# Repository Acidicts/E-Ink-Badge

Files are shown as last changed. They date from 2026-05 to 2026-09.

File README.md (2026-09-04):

# E-Ink Badge

A DIY Custom Designed, Monochrome, E-Ink display badge powered by the RP2350A, inspired by the GitHub Universe 2024 conference badge.
~Kinda wanted to see how many words I could describe it with. 

<div style="width:100%; display:inline-flex">
    E-Ink Badge render 1
    E-Ink Badge render 2
</div>

*(Renders made in Fusion 360)*

<div style="width:100%;">
    <div style="width:100%; display:inline-flex">
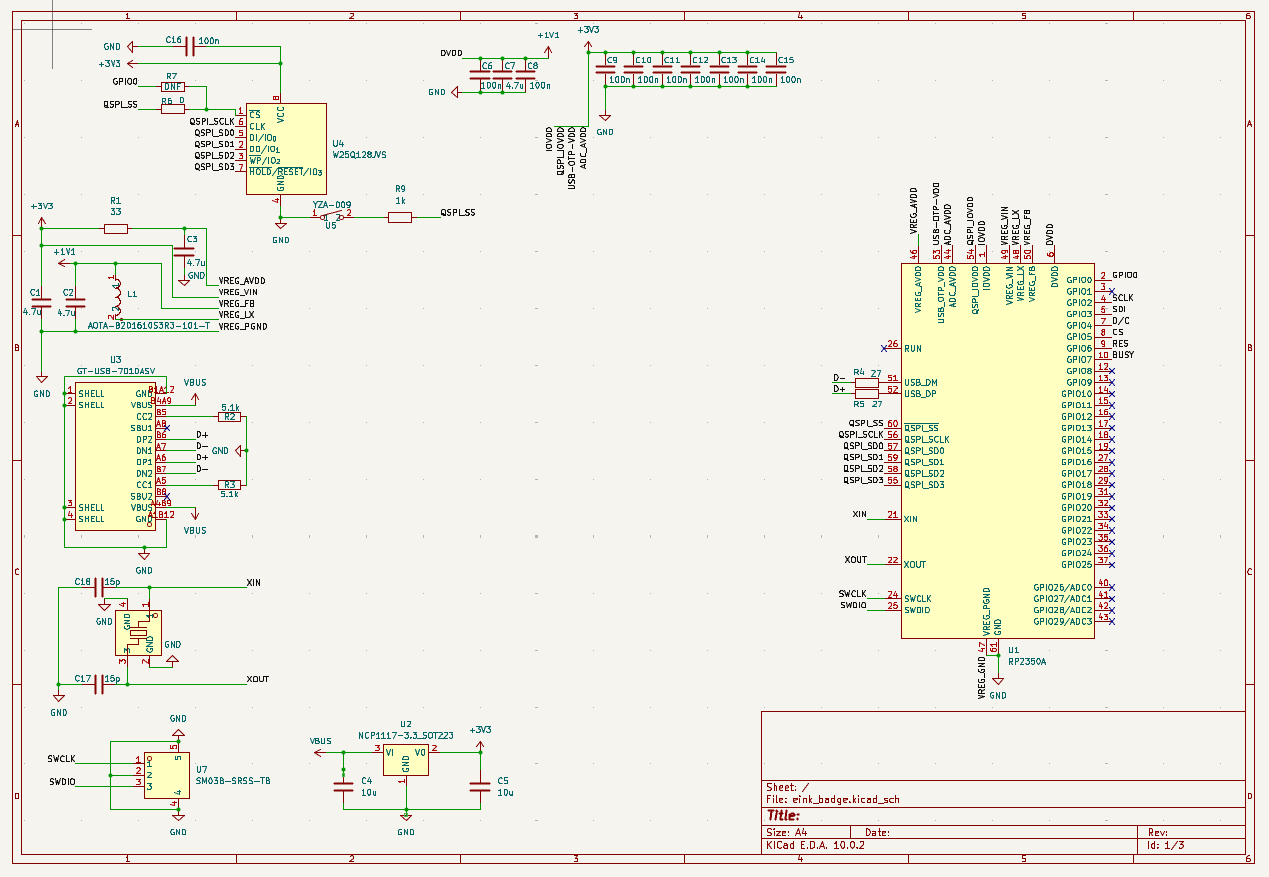
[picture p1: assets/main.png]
Assembled badge, main view
        
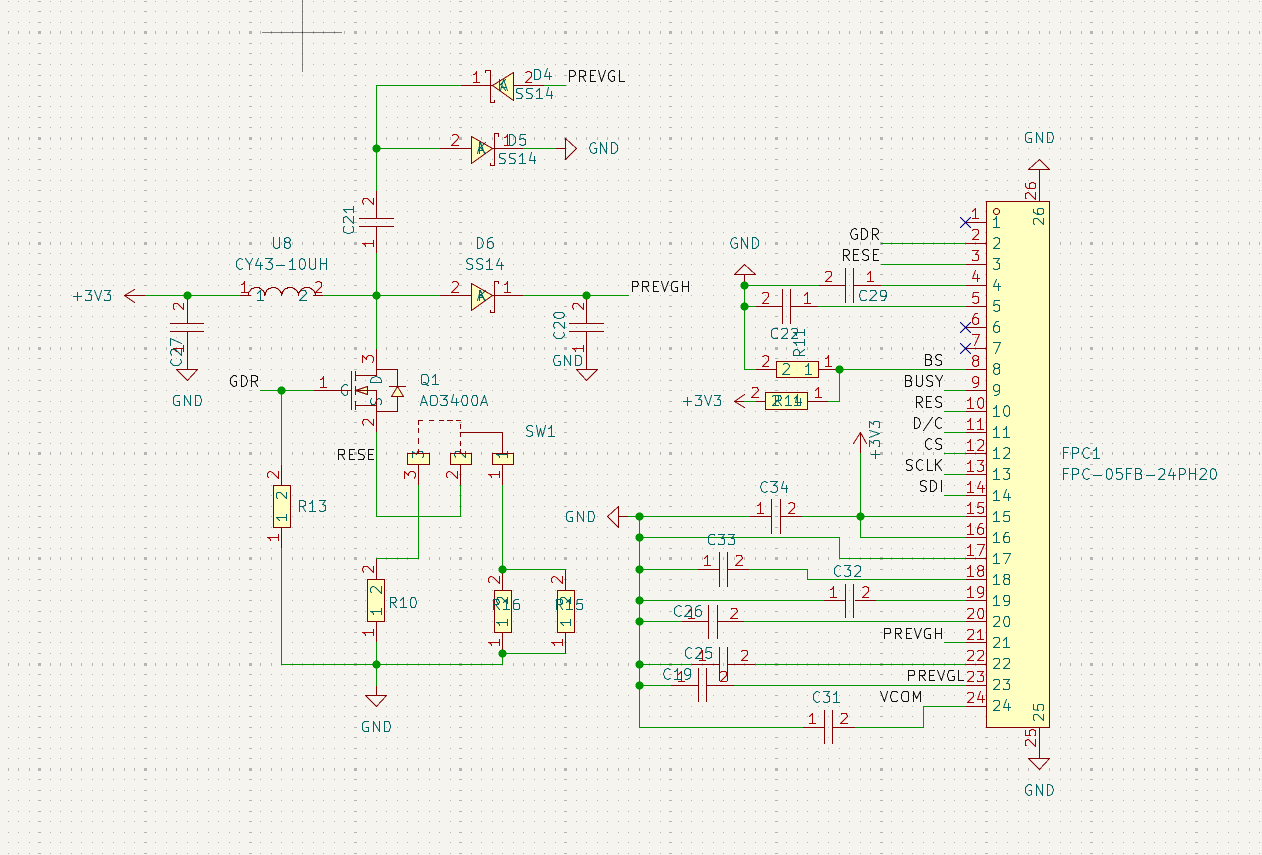
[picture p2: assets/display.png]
E-Ink display detail
        
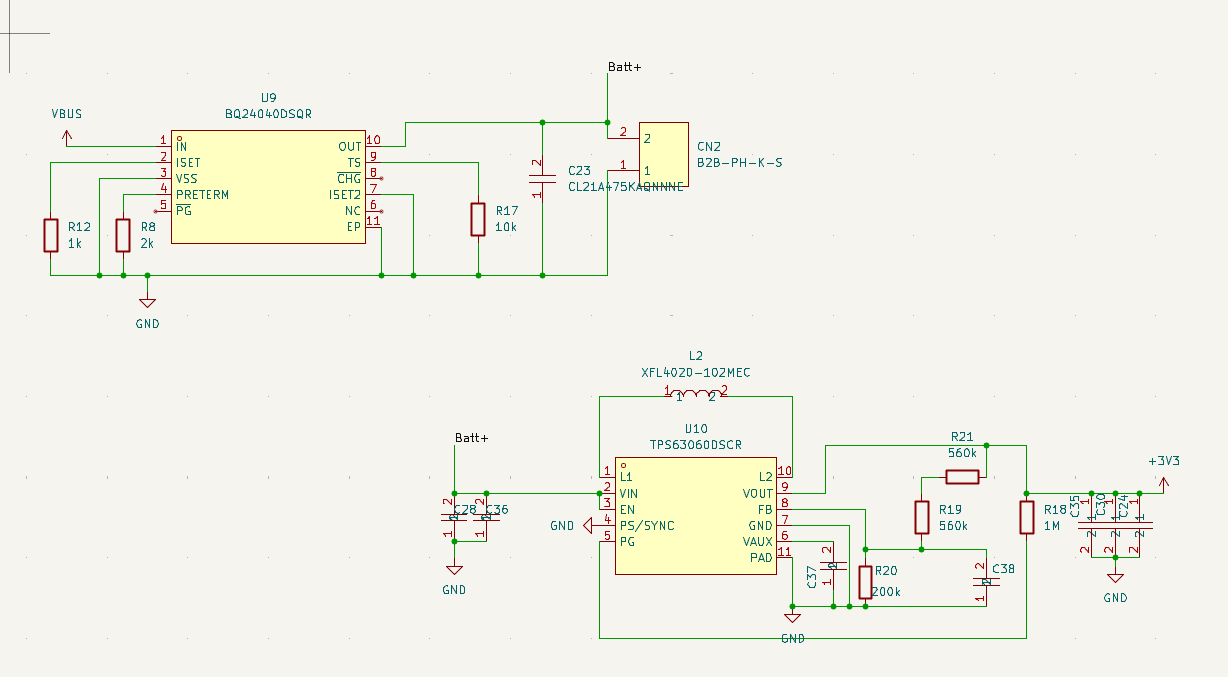
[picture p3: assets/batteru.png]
Battery mounting detail
        
    </div>
    <div style="width:100%; display:inline-flex">
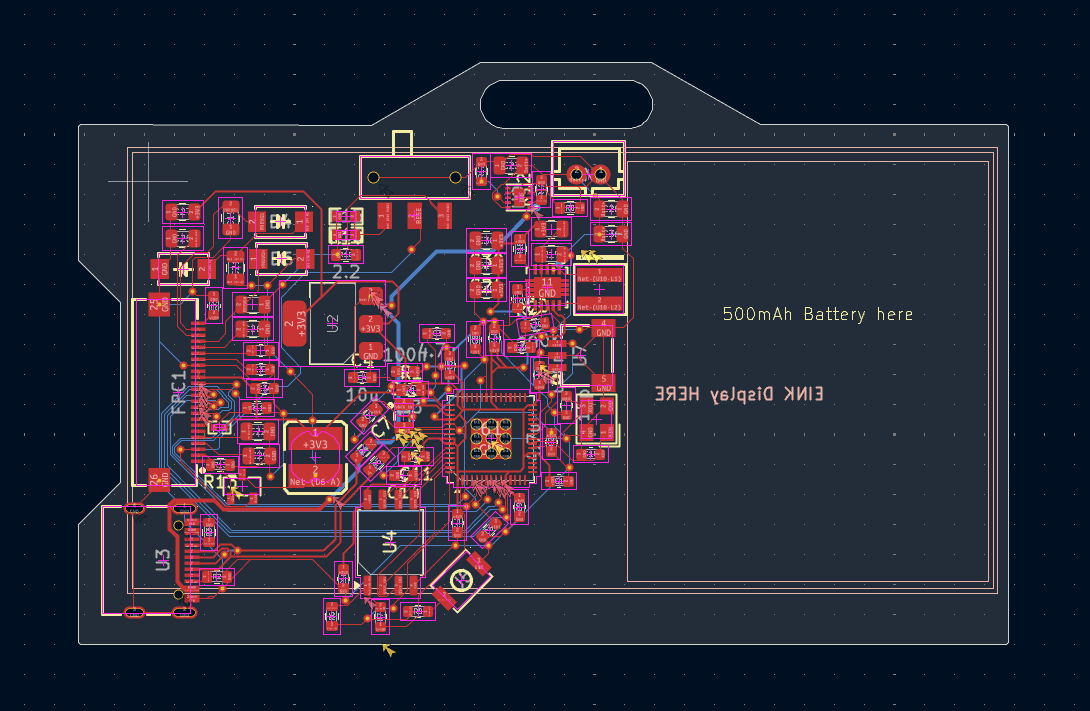
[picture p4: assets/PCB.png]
PCB layout
        
    </div>
</div>

## Features

- **MCU:** The mighty RP2350A I wish the RP2354A were in stock though
- **Flash:** 16MB onboard but do I want it to remember?
- **Power:** Integrated battery management for a single-cell LiPo, does it charge idk
- **Display:** E-Ink support over SPI, this was painful for part selection
- **Software:** No dedicated firmware/software yet — I'm considering adapting the [Badger 2040](https://github.com/pimoroni/badger2040) software from the GitHub Universe conference badge as a starting point, don't have the time for it

## Build Guide

This board has some fine-pitch and hand-soldering-unfriendly parts (the RP2350A and the E-Ink display's FPC connector), so I'd recommend using a **PCBA service** for the main board rather than hand-soldering it yourself. I know I wouldn't I have tried and failed, mainly cuz I dont have a hotplate.

Most components will already be populated(i liked this fancy word better than `placed`) by the assembly service — you'll only need to install the **battery** and the **display** yourself:

**Bring your own adhesive, please**
~ Not on BOM cuz not required for functionality

1. **Prepare the battery connector:** Trim the battery connector's legs slightly so they don't press against the back of the display once everything is assembled.
2. **Mount the battery:** Apply adhesive to the marked area on the PCB and stick the battery down.
3. **Connect the battery:** Plug the battery cable into the battery connector on the PCB.
4. **Mount the display:** Apply adhesive to the marked area on the front of the PCB and attach the E-Ink display. 
5. **Connect the display cable:** Route the ribbon cable through the indentation/slot in the PCB. Open the FPC connector's clamp arm, insert the ribbon cable, then press the clamp lever back down to lock it in place.

"That's it — the badge is fully assembled", I'd like to say, whether the firmware actually works, is what I'd like to know.

For getting started with software, I'd recommend flashing **CircuitPython**, as it's the easiest way to get up and running. Also have some demo firmware included in this repo, though it's untested/may not work out of the box.

## Firmware

I have some basic firmware in this repo. If you'd like to write your own, here are the SPI pin mappings for the display connection:

### SPI Pinout

| Signal | GPIO |
|---|---|
| SCLK (Clock) | GPIO 2 |
| SDI (MOSI/Data) | GPIO 3 |
| D/C (Data/Command)| GPIO 4 |
| CS (Chip Select)  | GPIO 5 |
| RES (Reset) | GPIO 6 |
| BUSY | GPIO 7 |

## Bill of Materials (BOM)

- [Project BOM](./BOM.csv) — full parts list for the badge
- [PCB BOM](./PCB_BOM.md) — parts list specific to the PCB assembly

### AI Usage Declaration 
- In part research
- Part finding (lcsc is hit or miss at finding stuff)
- Firmware Demo creation
- README Build Guide (code completion - fancy autocorrect ig)

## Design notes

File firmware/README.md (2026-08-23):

# E-Ink Badge — CircuitPython firmware

Firmware for the [E-Ink-Badge](https://github.com/) hardware: an RP2350A
board with a 360×184 SSD1680-class e-ink panel (GDEY0266T90H) over SPI,
BQ24040 LiPo charging, and a TPS63060 buck-boost rail.

This targets **CircuitPython**, not the Pico SDK / Arduino. It uses
`displayio` + Adafruit's `adafruit_ssd1680` driver.

## What you get

- Full-screen badge display: name / pronouns / role / handle, loaded from
  a plain-text profile file so you don't need to touch Python to
  personalize it.
- A tiny 2-button menu (Badge / Battery info / Sleep display).
- A battery icon + percentage in the corner, estimated from a LiPo
  discharge curve.
- Everything laid out in `displayio` groups so screens redraw cleanly.

## Hardware pin mapping (from GET_STARTED.md)

| Signal | GPIO |
|---|---|
| SCLK | 2 |
| SDI (MOSI) | 3 |
| D/C | 4 |
| CS | 5 |
| RES | 6 |
| BUSY | 7 |

These are wired up in `config.py`. Everything else — battery ADC pin,
charge-status pin, and the two menu buttons — **isn't documented in the
hardware README**, so `config.py` uses reasonable placeholder GPIOs
(GP26 for battery sense, GP10/GP11 for buttons) that you should double
check against your actual schematic/silkscreen and adjust if needed. If
your board doesn't route battery voltage to an ADC pin at all, set
`BATTERY_ADC_PIN = None` in `config.py` and the battery reading will
report "n/a" instead of a bogus number.

## Setup

1. **Flash CircuitPython** onto the RP2350A. Hold BOOTSEL while plugging
   in USB-C, then drag the appropriate `.uf2` for RP2350 onto the
   `RPI-RP2` drive that shows up. Get it from
   https://circuitpython.org/downloads (search for an RP2350-based board;
   if there's no exact board definition for this custom PCB, the generic
   `Raspberry Pi Pico 2` build is the right starting point since it's the
   same RP2350A/RP2350B family).

2. **Copy libraries.** Download the
   [Adafruit CircuitPython Bundle](https://circuitpython.org/libraries)
   matching your CircuitPython version, then copy these into a `lib/`
   folder on the `CIRCUITPY` drive:
   - `adafruit_ssd1680.mpy`
   - `adafruit_display_text/` (folder)
   - `fourwire.mpy` (only needed on older CircuitPython builds where it
     isn't built in — recent versions have `fourwire` built into the
     firmware itself, in which case you can skip this file)

3. **Copy this project's files** onto `CIRCUITPY`:
   - `boot.py`
   - `code.py`
   - `config.py`
   - `battery.py`
   - `buttons.py`
   - `badge_profile.py`
   - `badge_profile.txt`

4. **Personalize the badge** by editing `badge_profile.txt` directly on
   the `CIRCUITPY` drive — no code changes needed:
   ```
   name = Ada Lovelace
   pronouns = she/her
   role = Firmware
   handle = @ada
   ```

5. Power-cycle or save any file to trigger a reload. The badge will do a
   full refresh and show your badge screen.

## Controls

- You get none

## Notes / things you may want to change

- **Partial refresh**: `adafruit_ssd1680`'s stock `refresh()` always does
  a full (flashing) update. The status bar in the corner currently uses
  the same full refresh, on a 60-second timer, to keep things simple and
  dependency-light. If you want a snappier, non-flashing battery icon
  update, you'll need to either extend `adafruit_ssd1680` to expose the
  SSD1680's partial-refresh LUT/window commands directly, or drop down to
  raw `busio.SPI` + manual command bytes (the datasheet commands are
  `0x21`/`0x22` display update control + `0x44`/`0x45` RAM window +
  `0x24` write RAM + `0x20` master activate, with border waveform `0x3C`
  set to `0x80` for a partial, non-flashing update).
- **Deep sleep**: e-ink is bistable (holds its image with the panel fully
  powered off), so the "Sleep display" menu option here just stops
  issuing refreshes rather than needing to explicitly command the SSD1680
  into its deep-sleep register state. If you want to minimize current
  draw further, look at `alarm`/`microcontroller.deepsleep` in
  CircuitPython to put the RP2350 itself into a low-power state between
  button presses.
- **Battery sensing**: double-check `BATTERY_ADC_PIN` and
  `BATTERY_DIVIDER_RATIO` in `config.py` against your actual resistor
  divider before trusting the percentage shown.

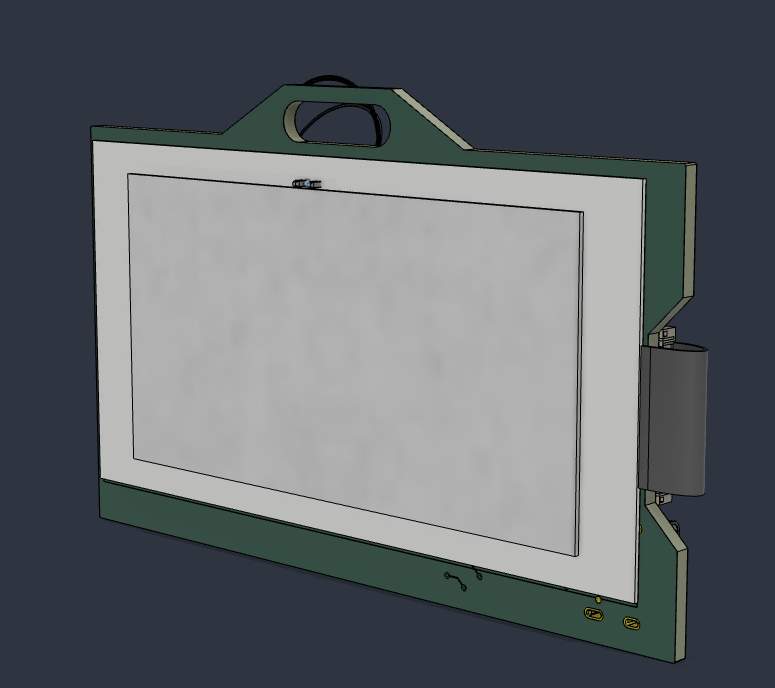
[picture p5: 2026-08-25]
assets/Render.png

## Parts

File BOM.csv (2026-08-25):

Item | Quantity | Cost ($) | Link
EInk Display | x1 | $6.30 | https://buyepaper.com/products/e-ink-display-high-resolution-gdey0266t90h?VariantsId=10607
Battery 3.7V / 500mAh | x1 | $8.50 | https://thepihut.com/products/500mah-3-7v-lipo-battery
PCB | x5 | $2-$4 | https://jlcpcb.com/
PCBA | x2 | $95.88 | https://jlcpcb.com/

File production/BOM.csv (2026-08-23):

Designator | Footprint | Quantity | Value | LCSC Part #
C1, C2, C3, C7 | 0603 | 4 | 4.7u
C10, C11, C12, C13, C14, C15, C16, C6, C8, C9 | 0603 | 10 | 100n
C17, C18 | 0603 | 2 | 15p
C19, C20, C21, C22, C23, C25, C26, C27, C29 | 0805 | 9 | CL21A475KAQNNNE | C1779
C24, C30, C35 | 0805 | 3 | 22uF | C92814
C28, C36 | 0805 | 2 | 10uF | C87157
C31, C32, C33, C34 | 0603 | 4 | 1uF | C15849
C37 | 0603 | 1 | 0.1uF
C38 | 0603 | 1 | 10pF | C1634
C4, C5 | 0603 | 2 | 10u
CN2 | CONN-TH_B2B-PH-K-S | 1 | B2B-PH-K-S | C131337
D4, D5, D6 | SMA_L4.2-W2.6-LS5.0-RD_1 | 3 | SS14 | C2480
FPC1 | FPC-SMD_24P-P0.50_FPC-05FB-24PH20 | 1 | FPC-05FB-24PH20 | C2856831
L1 | IND-SMD_L2.0-W1.6_AOTA-B201610S3R3-101-T | 1 | AOTA-B201610S3R3-101-T | C42411119
L2 | IND-SMD_L4.0-W4.0_XFL4020-102MEB | 1 | XFL4020-102MEC | C5355380
Q1 | SOT-23-3_L2.9-W1.3-P1.90-LS2.4-BR | 1 | AO3400A | C20917
R1 | 0603 | 1 | 33
R10, R11 | 0603 | 2 | 2.2 | C22939
R12, R9 | 0603 | 2 | 1k
R13 | 0603 | 1 | 10k | C115324
R14 | R0402 | 1 | 10k | C25744
R15, R16 | R0603 | 2 | 1 | C22936
R17 | 0603 | 1 | 10k | C98220
R18 | 0603 | 1 | 1M | C105578
R19, R21 | 0805 | 2 | 560k | C2933556
R2, R3 | 0603 | 2 | 5.1k
R20 | 0603 | 1 | 200k | C105574
R4, R5 | 0603 | 2 | 27
R6 | 0603 | 1 | 0
R7 | 0603 | 1 | DNF
R8 | 0603 | 1 | 2k | C140173
SW1 | SW-SMD_3P-L9.1-W3.5-P2.50_MST-12D18G2 | 1 | MST-12D18G2 SMD SLIDE SWITCH | C49023765
U1 | QFN-60-1EP_7x7mm_P0.4mm_EP3.4x3.4mm | 1 | RP2350A | C42411118
U10 | WSON-10_L3.0-W3.0-P0.50-BL-EP-A | 1 | TPS63060DSCR | C48567
U2 | SOT-223-3_TabPin2 | 1 | NCP1117-3.3_SOT223
U3 | USB-C-SMD_G-SWITCH_GT-USB-7010ASV | 1 | GT-USB-7010ASV | C2988369
U4 | SOIC-8_5.3x5.3mm_P1.27mm | 1 | W25Q128JVS
U5 | SW-SMD_YZA-009 | 1 | YZA-009 | C49108621
U6 | CRYSTAL-SMD_4P-L3.2-W2.5-BL | 1 | ABM8-272-T3_C20625731 | C20625731
U7 | CONN-SMD_SM03B-SRSS-TB-LF-SN-P | 1 | SM03B-SRSS-TB | C160403
U8 | IND-SMD_L4.5-W4.0 | 1 | CY43-10UH | C2929419
U9 | WSON-10_L2.0-W2.0-P0.40-BL-EP | 1 | BQ24040DSQR | C81080

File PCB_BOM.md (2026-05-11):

# BOM
### Note that this is for ~2 PCBA and some parts have min amount required

---

|	Comment	|	Designator	|	Footprint	|	JLCPCB Part #	|	Quantity	|	Total Cost	|
|	-----	|	---	|	---	|	---	|	----	|	---	|
|	AOTA-B201610S3R3-101-T	|	L1	|	IND-SMD_L2.0-W1.6_AOTA-B201610S3R3-101-T	|	C42411119	|	1	|	$1.4160	|
|	0603WAF220KT5E	|	R10,R11	|	R0603	|	C22939	|	2	|	$0.0108	|
|	33	|	R1	|	R_0402_1005Metric	|	C25105	|	1	|	$0.0018	|
|	LMK212BJ226MG-T	|	C24,C30,C35	|	C0805	|	C92814	|	3	|	$0.3430	|
|	CL10C100JB8NNNC	|	C38	|	C0603	|	C1634	|	1	|	$0.0106	|
|	RP2350A	|	U1	|	QFN-60-1EP_7x7mm_P0.4mm_EP3.4x3.4mm	|	C42411118	|	1	|	$2.5154	|
|	CL21A475KAQNNNE	|	C19,C20,C21,C22,C23,C25,C26,C27,C29	|	C0805	|	C1779	|	9	|	$0.2646	|
|	0603WAF100KT5E	|	R15,R16	|	R0603	|	C22936	|	2	|	$0.0088	|
|	560k	|	R19,R21	|	R_0805_2012Metric	|	C1404	|	2	|	$0.0380	|
|	0402WGF1002TCE	|	R13,R14	|	R0402	|	C25744	|	2	|	$0.0052	|
|	0	|	R6	|	R_0402_1005Metric	|	C17168	|	1	|	$0.0016	|
|	W25Q128JVS	|	U4	|	SOIC-8_5.3x5.3mm_P1.27mm	|	C97521	|	1	|	$4.9376	|
|	CY43-10UH	|	U8	|	IND-SMD_L4.5-W4.0	|	C2929419	|	1	|	$0.7940	|
|	XFL4020-102MEC	|	L2	|	IND-SMD_L4.0-W4.0_XFL4020-102MEB	|	C5355380	|	1	|	$2.2874	|
|	100n	|	C6,C8,C9,C10,C11,C12,C13,C14,C15,C16	|	C_0402_1005Metric	|	C1525	|	10	|	$0.0300	|
|	4.7u	|	C1,C2,C3,C7	|	C_0402_1005Metric	|	C23687	|	4	|	$0.3744	|
|	2k	|	R8	|	R_0402_1005Metric	|	C4109	|	1	|	$0.0016	|
|	200k	|	R20	|	R_0201_0603Metric	|	C49653632	|	1	|	$0.0100	|
|	FPC-05FB-24PH20	|	FPC1	|	FPC-SMD_24P-P0.50_FPC-05FB-24PH20	|	C2856831	|	1	|	$0.3974	|
|	YZA-009	|	U5	|	SW-SMD_YZA-009	|	C49108621	|	1	|	$0.0855	|
|	NCP1117-3.3_SOT223	|	U2	|	SOT-223-3_TabPin2	|	C6186	|	1	|	$0.4258	|
|	15p	|	C17,C18	|	C_0402_1005Metric	|	C1548	|	2	|	$0.0048	|
|	SS14	|	D4,D5,D6	|	SMA_L4.2-W2.6-LS5.0-RD_1	|	C2480	|	3	|	$0.1008	|
|	1M	|	R18	|	R_0603_1608Metric	|	C22935	|	1	|	$0.0030	|
|	1k	|	R9,R12	|	R_0402_1005Metric	|	C11702	|	2	|	$0.0040	|
|	SM03B-SRSS-TB	|	U7	|	CONN-SMD_SM03B-SRSS-TB-LF-SN-P	|	C160403	|	1	|	$1.0730	|
|	GT-USB-7010ASV	|	U3	|	USB-C-SMD_G-SWITCH_GT-USB-7010ASV	|	C2988369	|	1	|	$0.1732	|
|	ABM8-272-T3_C20625731	|	U6	|	CRYSTAL-SMD_4P-L3.2-W2.5-BL	|	C20625731	|	1	|	$1.4610	|
|	AO3400A	|	Q1	|	SOT-23-3_L2.9-W1.3-P1.90-LS2.4-BR	|	C20917	|	1	|	$0.1646	|
|	5.1k	|	R2,R3	|	R_0402_1005Metric	|	C25905	|	2	|	$0.0036	|
|	10k	|	R17	|	R_0603_1608Metric	|	C15401	|	1	|	$0.0220	|
|	EMK212BJ106KG-T	|	C28,C36	|	C0805	|	C87157	|	2	|	$0.4060	|
|	MST-12D18G2SMDSLIDESWITCH	|	SW1	|	SW-SMD_3P-L9.1-W3.5-P2.50_MST-12D18G2	|	C49023765	|	1	|	$0.3945	|
|	CL10A105KB8NNNC	|	C31,C32,C33,C34	|	C0603	|	C15849	|	4	|	$0.0608	|
|	BQ24040DSQR	|	U9	|	WSON-10_L2.0-W2.0-P0.40-BL-EP	|	C81080	|	1	|	$1.7075	|
|	10u	|	C4,C5	|	C_0805_2012Metric	|	C15850	|	2	|	$0.0824	|
|	CC0402KRX5R9BB104	|	C37	|	C0402	|	C307331	|	1	|	$0.0092	|
|	TPS63060DSCR	|	U10	|	WSON-10_L3.0-W3.0-P0.50-BL-EP-A	|	C48567	|	1	|	$3.7170	|
|	B2B-PH-K-S	|	CN2	|	CONN-TH_B2B-PH-K-S	|	C5251182	|	1	|	$1.2112	|
|	27	|	R4,R5	|	R_0402_1005Metric	|	C25100	|	2	|	$0.0160	|
|		|		|		|		|		|		|

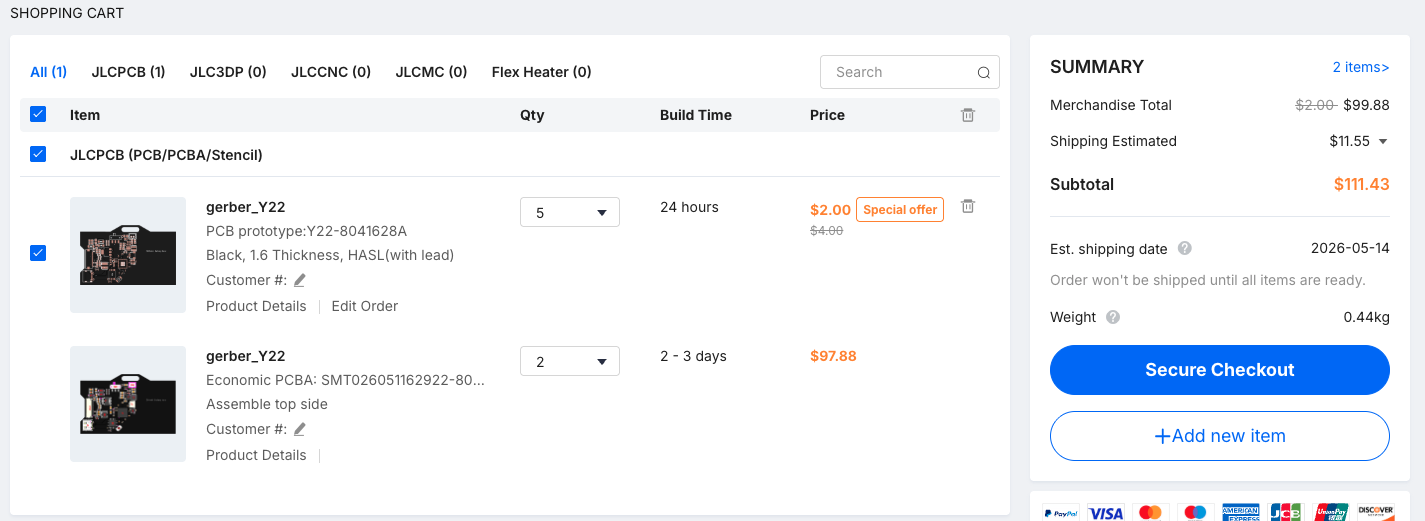
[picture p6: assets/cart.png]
cart


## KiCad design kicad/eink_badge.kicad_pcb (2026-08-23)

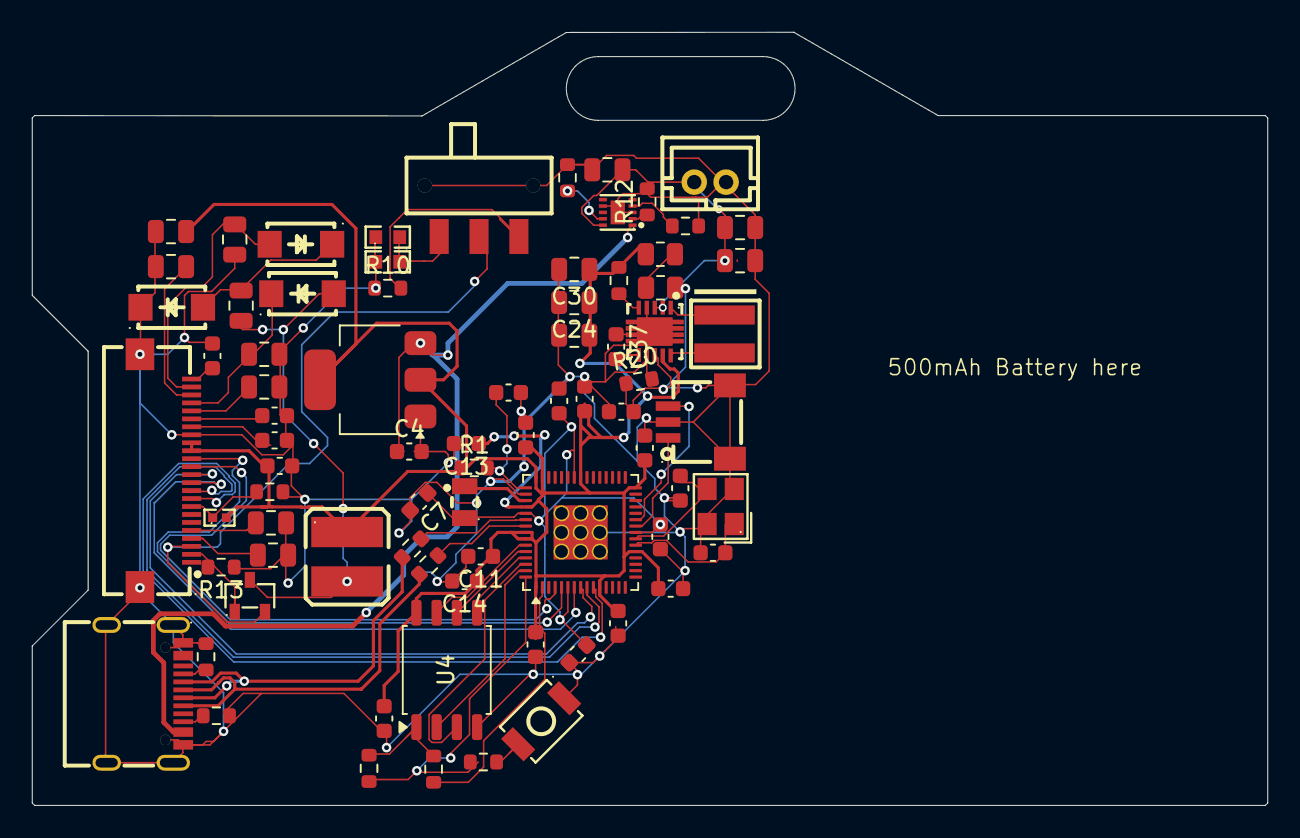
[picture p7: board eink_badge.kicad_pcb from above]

Board: 2 copper layers, 77.5 x 48.5 mm, 78 parts (0 on the bottom side), 51 nets.

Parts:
C1, C2, C3, C7: 4.7u; C_0603_1608Metric
C4, C5: 10u; C_0603_1608Metric
C6, C8, C9, C10, C11, C12, C13, C14, C15, C16: 100n; C_0603_1608Metric
C17, C18: 15p; C_0603_1608Metric
C19, C20, C21, C22, C23, C25, C26, C27, C29: CL21A475KAQNNNE; C_0805_2012Metric
C24, C30, C35: 22uF; C_0805_2012Metric
C28, C36: 10uF; C_0805_2012Metric
C31, C32, C33, C34: 1uF; C_0603_1608Metric
C37: 0.1uF; C_0603_1608Metric
C38: 10pF; C_0603_1608Metric
CN2: B2B-PH-K-S; CONN-TH_B2B-PH-K-S
D4, D5, D6: SS14; SMA_L4.2-W2.6-LS5.0-RD_1
FPC1: FPC-05FB-24PH20; FPC-SMD_24P-P0.50_FPC-05FB-24PH20
L1: AOTA-B201610S3R3-101-T; IND-SMD_L2.0-W1.6_AOTA-B201610S3R3-101-T
L2: XFL4020-102MEC; IND-SMD_L4.0-W4.0_XFL4020-102MEB
Q1: AO3400A; SOT-23-3_L2.9-W1.3-P1.90-LS2.4-BR
R1: 33; R_0603_1608Metric
R2, R3: 5.1k; R_0603_1608Metric
R4, R5: 27; R_0603_1608Metric
R6: 0; R_0603_1608Metric
R7: DNF; R_0603_1608Metric
R8: 2k; R_0603_1608Metric
R9, R12: 1k; R_0603_1608Metric
R10, R11: 2.2; R_0603_1608Metric
R13, R17: 10k; R_0603_1608Metric
R14: 10k; R0402
R15, R16: 1; R0603
R18: 1M; R_0603_1608Metric
R19, R21: 560k; R_0805_2012Metric
R20: 200k; R_0603_1608Metric
SW1: MST-12D18G2 SMD SLIDE SWITCH; SW-SMD_3P-L9.1-W3.5-P2.50_MST-12D18G2
U1: RP2350A; QFN-60-1EP_7x7mm_P0.4mm_EP3.4x3.4mm
U2: NCP1117-3.3_SOT223; SOT-223-3_TabPin2
U3: GT-USB-7010ASV; USB-C-SMD_G-SWITCH_GT-USB-7010ASV
U4: W25Q128JVS; SOIC-8_5.3x5.3mm_P1.27mm
U5: YZA-009; SW-SMD_YZA-009
U6: ABM8-272-T3_C20625731; CRYSTAL-SMD_4P-L3.2-W2.5-BL
U7: SM03B-SRSS-TB; CONN-SMD_SM03B-SRSS-TB-LF-SN-P
U8: CY43-10UH; IND-SMD_L4.5-W4.0
U9: BQ24040DSQR; WSON-10_L2.0-W2.0-P0.40-BL-EP
U10: TPS63060DSCR; WSON-10_L3.0-W3.0-P0.50-BL-EP-A

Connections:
+1V1: C2.1, C6.1, C7.1, C8.1, L1.1, U1.6 (DVDD), U1.23 (DVDD), U1.39 (DVDD), U1.50 (VREG_FB)
+3V3: C1.1, C5.1, C9.1, C10.1, C11.1, C12.1, C13.1, C14.1, C15.1, C16.1, C24.1, C27.2, C30.1, C34.2, C35.1, FPC1.15, FPC1.16, R1.1, R14.2, R18.1, R21.1, U1.1 (IOVDD), U1.11 (IOVDD), U1.20 (IOVDD), U1.30 (IOVDD), U1.38 (IOVDD), U1.44 (ADC_AVDD), U1.45 (IOVDD), U1.49 (VREG_VIN), U1.53 (USB_OTP_VDD), U1.54 (QSPI_IOVDD), U2.2 (VO), U4.8 (VCC), U8.1, U10.9 (VOUT)
/Battery Charger/Batt+: C23.2, C28.2, C36.2, CN2.2, U9.10 (OUT), U10.2 (VIN), U10.3 (EN)
/E Ink/BS: FPC1.8, R11.1, R14.1
/E Ink/GDR: FPC1.2, Q1.1 (G), R13.2
/E Ink/PREVGH: C20.2, D6.1 (K), FPC1.21
/E Ink/PREVGL: C19.2, D4.2 (A), FPC1.23
/E Ink/RESE: FPC1.3, Q1.2 (S), SW1.2
/E Ink/VCOM: C31.2, FPC1.24
/Root/D+: R5.1, U3.A6 (DP1), U3.B6 (DP2)
/Root/D-: R4.1, U3.A7 (DN1), U3.B7 (DN2)
/Root/GPIO0: R7.1, U1.2 (GPIO0)
/Root/QSPI_SCLK: U1.56 (QSPI_SCLK), U4.6 (CLK)
/Root/QSPI_SD0: U1.57 (QSPI_SD0), U4.5 (DI/IO_{0})
/Root/QSPI_SD1: U1.59 (QSPI_SD1), U4.2 (DO/IO_{1})
/Root/QSPI_SD2: U1.58 (QSPI_SD2), U4.3 (~WP/IO_{2})
/Root/QSPI_SD3: U1.55 (QSPI_SD3), U4.7 (~HOLD/~RESET/IO_{3})
/Root/QSPI_SS: R6.1, R9.2, U1.60 (~QSPI_SS)
/Root/SWCLK: U1.24 (SWCLK), U7.1
/Root/SWDIO: U1.25 (SWDIO), U7.3
/Root/VREG_AVDD: C3.1, R1.2, U1.46 (VREG_AVDD)
/Root/VREG_LX: L1.2, U1.48 (VREG_LX)
/Root/XIN: C18.2, U1.21 (XIN), U6.1
/Root/XOUT: C17.2, U1.22 (XOUT), U6.3
GND: C1.2, C2.2, C3.2, C4.2, C5.2, C6.2, C7.2, C8.2, C9.2, C10.2, C11.2, C12.2, C13.2, C14.2, C15.2, C16.2, C17.1, C18.1, C19.1, C20.1, C22.2, C23.1, C24.2, C25.1, C26.1, C27.1, C28.1, C29.2, C30.2, C31.1, C32.1, C33.1, C34.1, C35.2, C36.1, C37.1, C38.1, CN2.1, D5.1 (K), FPC1.17, FPC1.25, FPC1.26, R2.2, R3.2, R8.2, R10.1, R11.2, R12.2, R13.1, R15.1, R16.1, R17.2, R20.2, U1.47 (VREG_PGND), U1.61 (GND), U2.1 (GND), U3.1 (SHELL), U3.2 (SHELL), U3.3 (SHELL), U3.4 (SHELL), U3.A1B12 (GND), U3.B1A12 (GND), U4.4 (GND), U5.1, U6.2 (GND), U6.4 (GND), U7.2, U7.4, U7.5, U9.3 (VSS), U9.7 (ISET2), U9.11 (EP), U10.4 (PS/SYNC), U10.7 (GND), U10.11 (PAD)
unnamed: C22.1, FPC1.5
unnamed: C25.2, FPC1.22
unnamed: C26.2, FPC1.20
unnamed: C29.1, FPC1.4
unnamed: C32.2, FPC1.19
unnamed: C33.2, FPC1.18
unnamed: C21.2, D4.1 (K), D5.2 (A)
unnamed: C21.1, D6.2 (A), Q1.3 (D), U8.2
unnamed: R9.1, U5.2
unnamed: R10.2, SW1.3
unnamed: R15.2, R16.2, SW1.1
unnamed: R19.1, R21.2
unnamed: R4.2, U1.51 (USB_DM)
unnamed: R5.2, U1.52 (USB_DP)
unnamed: C4.1, U2.3 (VI)
unnamed: R3.1, U3.A5 (CC1)
unnamed: R2.1, U3.B5 (CC2)
unnamed: R6.2, R7.2, U4.1 (~CS)
unnamed: R12.1, U9.2 (ISET)
unnamed: R8.1, U9.4 (PRETERM)
unnamed: R17.1, U9.9 (TS)
unnamed: C38.2, R19.2, R20.1, U10.8 (FB)
unnamed: L2.1, U10.1 (L1)
unnamed: L2.2, U10.10 (L2)
unnamed: R18.2, U10.5 (PG)
unnamed: C37.2, U10.6 (VAUX)

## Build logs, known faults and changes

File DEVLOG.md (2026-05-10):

# Custom E-Ink Badge

A custom e-ink badge inspired by github universe 2024 conference badge

# 2026-05-10: Final Image Renders

**Total time spent: 0 hours**

I made my final renders of the board in fusion 360




# 2026-05-10: Added battery to fusion 360 model

**Total time spent: 0.5 hours**

I add the battery to my fusion 360 project with same [animation](https://a360.co/4tpzNeO) but now with the battery. I also touched up the pcb a bit



# 2026-05-10: Added Lipo Battery Management

**Total time spent: 2 hours**

I found and added Lipo battery charging and powering for the board, using a [3.7V / 500mAh Lipo battery](https://thepihut.com/products/500mah-3-7v-lipo-battery)





# 2026-05-10: Made the Display in Fusion 360 and made fun lil animation

**Total time spent: 1 hour**

I went on fusion 360 and made an animation and the whole project so far. Creating the display aswell.

Animation [here](https://a360.co/4uIv896) 



# 2026-05-09: Added the Eink display stuff onto the pcb

**Total time spent: 3 hours**

I finished the pcb for the most part now I just need to add art and other fun things to it maybe mounting holes and battery support




# 2026-05-09: Made Schematic for the eink display

**Total time spent: 2 hours**

I looked through different parts and different documentation and tutorials to make the connection circuit.
I also decided on using [this](https://buyepaper.com/products/e-ink-display-high-resolution-gdey0266t90h?VariantsId=10607) display due to cost and the documentation being in english



# 2026-05-09: Designed Base PCB Layout

**Total time spent: 3 hours**

I made the base RP2350A board using:
- A USB C Port
- A Bootsel Button (Tactile Button)
- RP2350A
- 128Mbit flash
- 8mhz clock
- JST Debug Connector
- LVD
and a buncha Resistors and Capacitors

Now I need to figure out the eink display part




# 2026-05-09: Designed the base schematic

**Total time spent: 3 hours**

I made the schematic with use of the hardware design for RP235X
I used the RP2350A with the recommended parts
 


# 2026-05-09: Looked at the RP235x Design Guide

**Total time spent: 1 hour**

I looked at a the RP235x design guide to make my base devboard before adding in the eink display.
I also looked on lcsc to look for parts stock and installed Kicad and easyeda2kicad


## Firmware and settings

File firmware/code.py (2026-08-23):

# code.py - E-Ink Badge firmware (CircuitPython).
#
# Requires these libraries copied into /lib on CIRCUITPY (from the Adafruit
# CircuitPython Bundle matching your CircuitPython version):
#   adafruit_ssd1680.mpy
#   fourwire.mpy            (built into recent CircuitPython; if your build
#                             doesn't have it, use `displayio.FourWire`
#                             instead - see the commented alternative below)
#   adafruit_display_text/  (folder, for label.Label)
#
# Behavior:
#   - Boots, loads /badge_profile.txt, draws the badge screen (full
#     refresh).
#   - Button A: open a simple menu (Badge / Battery / Sleep display).
#   - Button B: confirm menu selection / force full refresh on badge
#     screen.
#   - Battery icon in the corner updates periodically via a fast partial
#     refresh so it doesn't need a full flashing redraw.

import time
import gc

import busio
import displayio
import terminalio
from adafruit_display_text import label

try:
    from fourwire import FourWire
except ImportError:
    from displayio import FourWire

import adafruit_ssd1680

import config
import battery
import badge_profile
from buttons import Button

displayio.release_displays()

# ---------------------------------------------------------------------
# Display bring-up
# ---------------------------------------------------------------------
spi = busio.SPI(clock=config.EPD_SCLK, MOSI=config.EPD_MOSI)

display_bus = FourWire(
    spi,
    command=config.EPD_DC,
    chip_select=config.EPD_CS,
    reset=config.EPD_RESET,
    baudrate=config.EPD_BAUDRATE,
)

display = adafruit_ssd1680.SSD1680(
    display_bus,
    width=config.EPD_WIDTH,
    height=config.EPD_HEIGHT,
    busy_pin=config.EPD_BUSY,
    rotation=0,
    # This is a monochrome panel (GDEY0266T90H), so no highlight_color.
)

# ---------------------------------------------------------------------
# Battery + buttons
# ---------------------------------------------------------------------
chg_pin = None
if config.BATTERY_CHG_STAT_PIN is not None:
    import digitalio

    chg_pin = digitalio.DigitalInOut(config.BATTERY_CHG_STAT_PIN)
    chg_pin.switch_to_input(pull=digitalio.Pull.UP)

batt = battery.Battery(
    adc_pin=config.BATTERY_ADC_PIN,
    divider_ratio=config.BATTERY_DIVIDER_RATIO,
    charging_pin=chg_pin,
)

btn_a = Button(config.BUTTON_A_PIN, active_low=config.BUTTONS_ACTIVE_LOW)
btn_b = Button(config.BUTTON_B_PIN, active_low=config.BUTTONS_ACTIVE_LOW)

profile = badge_profile.load()

# ---------------------------------------------------------------------
# Screens
# ---------------------------------------------------------------------

WHITE = 0xFFFFFF
BLACK = 0x000000

PALETTE = displayio.Palette(2)
PALETTE[0] = WHITE
PALETTE[1] = BLACK


def solid_bitmap(w, h, color_index):
    bmp = displayio.Bitmap(w, h, 2)
    bmp.fill(color_index)
    return bmp


def make_badge_group():
    group = displayio.Group()

    # White background covering the whole panel.
    bg = displayio.TileGrid(
        solid_bitmap(config.EPD_WIDTH, config.EPD_HEIGHT, 0), pixel_shader=PALETTE
    )
    group.append(bg)

    # Header bar (black strip across the top).
    header_h = 22
    header = displayio.TileGrid(
        solid_bitmap(config.EPD_WIDTH, header_h, 1), pixel_shader=PALETTE
    )
    group.append(header)

    header_label = label.Label(
        terminalio.FONT, text="E-INK BADGE", color=WHITE, x=10, y=header_h // 2
    )
    group.append(header_label)

    margin = 12
    y = 44

    name_label = label.Label(
        terminalio.FONT,
        text=profile["name"],
        color=BLACK,
        scale=3,
        x=margin,
        y=y,
    )
    group.append(name_label)
    y += 34

    line2 = "{}  |  {}".format(profile["pronouns"], profile["role"])
    line2_label = label.Label(terminalio.FONT, text=line2, color=BLACK, x=margin, y=y)
    group.append(line2_label)
    y += 16

    # Divider line.
    divider = displayio.TileGrid(
        solid_bitmap(config.EPD_WIDTH - 2 * margin, 1, 1),
        pixel_shader=PALETTE,
        x=margin,
        y=y,
    )
    group.append(divider)
    y += 12

    handle_label = label.Label(
        terminalio.FONT, text=profile["handle"], color=BLACK, scale=2, x=margin, y=y
    )
    group.append(handle_label)

    footer_label = label.Label(
        terminalio.FONT,
        text="hold A: menu   B: refresh",
        color=BLACK,
        x=margin,
        y=config.EPD_HEIGHT - 10,
    )
    group.append(footer_label)

    # Status bar group (battery icon + %), kept as a sub-group so it can be
    # rebuilt independently for partial refreshes without touching the
    # rest of the badge layout.
    status_group = displayio.Group()
    group.append(status_group)

    return group, status_group


STATUS_W = 70
STATUS_H = 18
STATUS_X = config.EPD_WIDTH - STATUS_W - 4
STATUS_Y = 3


def draw_battery_icon_bitmap(percent, charging):
    """Return a small bitmap with a battery glyph + percent text baked in
    as raw pixels via simple rectangle fills (keeps this dependency-free -
    no extra image assets needed)."""
    bmp = displayio.Bitmap(STATUS_W, STATUS_H, 2)
    bmp.fill(0)  # white background

    body_x, body_y, body_w, body_h = 0, 2, 26, 13
    tip_w, tip_h = 3, 6

    def rect(x, y, w, h, val):
        for yy in range(max(0, y), min(STATUS_H, y + h)):
            for xx in range(max(0, x), min(STATUS_W, x + w)):
                bmp[xx, yy] = val

    def rect_outline(x, y, w, h, val):
        rect(x, y, w, 1, val)
        rect(x, y + h - 1, w, 1, val)
        rect(x, y, 1, h, val)
        rect(x + w - 1, y, 1, h, val)

    rect_outline(body_x, body_y, body_w, body_h, 1)
    rect(body_x + body_w, body_y + (body_h - tip_h) // 2, tip_w, tip_h, 1)

    pct = max(0, min(100, percent))
    inner_w = body_w - 4
    fill_w = int(inner_w * pct / 100)
    if fill_w > 0:
        rect(body_x + 2, body_y + 2, fill_w, body_h - 4, 1)

    return bmp


def make_status_content(percent, charging):
    grp = displayio.Group()
    icon_bmp = draw_battery_icon_bitmap(percent, charging)
    icon_tile = displayio.TileGrid(icon_bmp, pixel_shader=PALETTE, x=STATUS_X, y=STATUS_Y)
    grp.append(icon_tile)

    pct_text = "?" if percent < 0 else "{}%".format(percent)
    pct_label = label.Label(
        terminalio.FONT, text=pct_text, color=BLACK, x=STATUS_X + 34, y=STATUS_Y + 9
    )
    grp.append(pct_label)
    return grp


def update_status(status_group, percent, charging):
    while len(status_group) > 0:
        status_group.pop()
    status_group.append(make_status_content(percent, charging))


def make_menu_group(title, items, selected):
    group = displayio.Group()

    bg = displayio.TileGrid(
        solid_bitmap(config.EPD_WIDTH, config.EPD_HEIGHT, 0), pixel_shader=PALETTE
    )
    group.append(bg)

    header_h = 20
    header = displayio.TileGrid(
        solid_bitmap(config.EPD_WIDTH, header_h, 1), pixel_shader=PALETTE
    )
    group.append(header)
    group.append(label.Label(terminalio.FONT, text=title, color=WHITE, x=10, y=header_h // 2))

    margin = 10
    y = 34
    row_h = 18
    for i, item in enumerate(items):
        if i == selected:
            highlight = displayio.TileGrid(
                solid_bitmap(config.EPD_WIDTH - 2 * (margin - 2), row_h - 2, 1),
                pixel_shader=PALETTE,
                x=margin - 2,
                y=y - row_h // 2,
            )
            group.append(highlight)
            group.append(label.Label(terminalio.FONT, text=item, color=WHITE, x=margin, y=y))
        else:
            group.append(label.Label(terminalio.FONT, text=item, color=BLACK, x=margin, y=y))
        y += row_h

    return group


def make_battery_screen_group():
    group = displayio.Group()
    bg = displayio.TileGrid(
        solid_bitmap(config.EPD_WIDTH, config.EPD_HEIGHT, 0), pixel_shader=PALETTE
    )
    group.append(bg)

    header_h = 20
    header = displayio.TileGrid(
        solid_bitmap(config.EPD_WIDTH, header_h, 1), pixel_shader=PALETTE
    )
    group.append(header)
    group.append(label.Label(terminalio.FONT, text="BATTERY", color=WHITE, x=10, y=header_h // 2))

    v = batt.read_voltage()
    pct = batt.read_percent()
    charging = batt.is_charging()

    lines = [
        "Voltage: {}".format("{:.2f} V".format(v) if v is not None else "n/a"),
        "Charge:  {}".format("{}%".format(pct) if pct >= 0 else "n/a"),
        "Status:  {}".format(
            "Charging" if charging else ("On battery" if charging is False else "n/a")
        ),
    ]
    y = 46
    for line in lines:
        group.append(label.Label(terminalio.FONT, text=line, color=BLACK, x=10, y=y))
        y += 18

    group.append(
        label.Label(terminalio.FONT, text="A: back", color=BLACK, x=10, y=config.EPD_HEIGHT - 10)
    )
    return group


# ---------------------------------------------------------------------
# State machine
# ---------------------------------------------------------------------

SCREEN_BADGE = "badge"
SCREEN_MENU = "menu"
SCREEN_BATTERY = "battery"

MENU_ITEMS = ["Badge", "Battery info", "Sleep display"]

state = {"screen": SCREEN_BADGE, "menu_selected": 0}

badge_group, badge_status_group = make_badge_group()


def show_badge(full_refresh=True):
    update_status(badge_status_group, batt.read_percent(), batt.is_charging())
    display.root_group = badge_group
    display.refresh()
    if not full_refresh:
        # adafruit_ssd1680's refresh() always does a full update in the
        # stock driver; partial-refresh windowing isn't exposed at this
        # layer. We still call refresh() here - see NOTE below for how to
        # add true partial refresh if you need faster status-bar-only
        # updates.
        pass


def show_menu():
    display.root_group = make_menu_group("MENU", MENU_ITEMS, state["menu_selected"])
    display.refresh()


def show_battery():
    display.root_group = make_battery_screen_group()
    display.refresh()


def wait_for_display_ready():
    # adafruit_ssd1680 already waits on BUSY internally during refresh(),
    # but time_to_refresh gives a hint for how long the caller should
    # avoid issuing another refresh.
    try:
        time.sleep(display.time_to_refresh)
    except AttributeError:
        time.sleep(2)


# ---------------------------------------------------------------------
# Boot
# ---------------------------------------------------------------------
print("E-Ink Badge booting:", profile["name"], profile["handle"])
show_badge(full_refresh=True)

next_status_update = time.monotonic() + 60  # refresh battery icon every 60s

while True:
    btn_a.poll()
    btn_b.poll()

    if btn_a.was_pressed():
        if state["screen"] == SCREEN_BADGE:
            state["screen"] = SCREEN_MENU
            state["menu_selected"] = 0
            show_menu()
        elif state["screen"] == SCREEN_MENU:
            state["menu_selected"] = (state["menu_selected"] + 1) % len(MENU_ITEMS)
            show_menu()
        elif state["screen"] == SCREEN_BATTERY:
            state["screen"] = SCREEN_BADGE
            show_badge(full_refresh=True)

    if btn_b.was_pressed():
        if state["screen"] == SCREEN_BADGE:
            show_badge(full_refresh=True)
        elif state["screen"] == SCREEN_MENU:
            sel = state["menu_selected"]
            if sel == 0:
                state["screen"] = SCREEN_BADGE
                show_badge(full_refresh=True)
            elif sel == 1:
                state["screen"] = SCREEN_BATTERY
                show_battery()
            elif sel == 2:
                print("Sleeping display. Press any button to wake.")
                # SSD1680-family panels: putting the MCU to sleep is
                # separate from the panel's own deep-sleep state, which
                # the adafruit_ssd1680 driver doesn't expose directly.
                # Simplest reliable approach: just stop refreshing and
                # wait for input; the panel holds its image with no power
                # either way since e-ink is bistable.
                while True:
                    btn_a.poll()
                    btn_b.poll()
                    if btn_a.was_pressed() or btn_b.was_pressed():
                        break
                    time.sleep(0.05)
                state["screen"] = SCREEN_BADGE
                show_badge(full_refresh=True)
        elif state["screen"] == SCREEN_BATTERY:
            state["screen"] = SCREEN_BADGE
            show_badge(full_refresh=True)

    if state["screen"] == SCREEN_BADGE and time.monotonic() >= next_status_update:
        update_status(badge_status_group, batt.read_percent(), batt.is_charging())
        display.refresh()
        next_status_update = time.monotonic() + 60

    gc.collect()
    time.sleep(0.02)

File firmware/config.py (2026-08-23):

# config.py - pin mapping for the E-Ink Badge (RP2350A), from GET_STARTED.md.
#
#   SPI display pins:
#     SCLK  -> GPIO 2
#     SDI   -> GPIO 3   (MCU -> display, "MOSI")
#     D/C   -> GPIO 4
#     CS    -> GPIO 5
#     RES   -> GPIO 6
#     BUSY  -> GPIO 7
#
# Everything else (battery ADC channel, buttons) isn't called out in the
# hardware docs, so sensible defaults are used below and clearly marked.
# Adjust to match your actual schematic/silkscreen if they differ.

import board

# ---- E-ink display (SSD1680-class controller, GDEY0266T90H 360x184) ----
EPD_SCLK = board.GP2
EPD_MOSI = board.GP3
EPD_DC = board.GP4
EPD_CS = board.GP5
EPD_RESET = board.GP6
EPD_BUSY = board.GP7

EPD_WIDTH = 360
EPD_HEIGHT = 184
EPD_BAUDRATE = 4_000_000  # 4 MHz, safe for SSD1680

# ---- Battery / power management (BQ24040 charger + TPS63060 buck-boost) --
# No ADC pin is documented for battery sensing in GET_STARTED.md. GP26/ADC0
# is used here as a reasonable default free pin; change to match your
# schematic, or set to None if VBAT isn't routed to the MCU at all.
BATTERY_ADC_PIN = board.GP26
BATTERY_DIVIDER_RATIO = 2.0  # Vbat = Vadc * ratio

# BQ24040 STAT pin (open-drain, active-low while charging) - optional.
# Set to a board.GPxx if wired, or None to disable charge-status reporting.
BATTERY_CHG_STAT_PIN = None

# ---- User input ----
# The board has a BOOTSEL button used for UF2 flashing, not available as a
# normal GPIO to running code. No dedicated user buttons are documented in
# GET_STARTED.md - wire tactile buttons to spare GPIOs and adjust here.
BUTTON_A_PIN = board.GP10
BUTTON_B_PIN = board.GP11
BUTTONS_ACTIVE_LOW = True

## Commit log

2026-05-10 Repo Refactoring
    [BOM.csv, battery_charger.kicad_sch, eink_badge.kicad_pcb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]
2026-05-11 Refactor code structure for improved readability and maintainability
    [BOM.csv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]
2026-08-23 Changed to use foorprint of 0603 0805 1005 metric for resistors and capacitors where possible
    [BOM.csv, battery_charger.kicad_sch, eink_badge.kicad_pcb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]
2026-08-25 file upload
    [BOM.csv]
